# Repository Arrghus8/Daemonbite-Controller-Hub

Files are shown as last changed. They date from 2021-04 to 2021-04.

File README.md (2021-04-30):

# Daemonbite-Controller-Hub

daemonbite-controller-hub

This is an add-on board for the MiSTer FPGA project to provide original hardware inputs for SNES, NES and Genesis controllers using Daemonbite adapters (see https://github.com/MickGyver/DaemonBite-Retro-Controllers-USB). The current version serves only as a mount for the Arduinos and controller ports.

# Parts needed (v0.1):

- 2x Pro Micro ATmega32U4 (micro USB): https://www.aliexpress.com/item/1005001335338291.html
- 2x Micro USB cable: https://www.aliexpress.com/item/4000378492248.html
- 2x DB9 male port: https://www.aliexpress.com/item/33047048440.html
- 2x SNES port (90 degree): https://www.aliexpress.com/item/32838396935.html
- 2x NES port (90 degree): https://www.aliexpress.com/item/32875874969.html
- 4x M3 Male 6mm x M3 Female 20mm Standoff: https://www.aliexpress.com/item/32667773402.html

# Roadmap

- Integrate ATmega32U4 directly on board
- Integrate 7-port powered USB hub to board

# Issues

- Need to verify that 4 controllers (2x SNES and 2x NES) can be run through a single Pro Micro (see https://github.com/MickGyver/DaemonBite-Retro-Controllers-USB/issues/3).

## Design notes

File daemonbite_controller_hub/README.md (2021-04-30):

KiCad Version: (5.99.0-9987-g41839f7e3f), release build

<code>ARDUINO PRO MICRO.STEP</code> taken from https://grabcad.com/library/arduino-pro-micro-1.

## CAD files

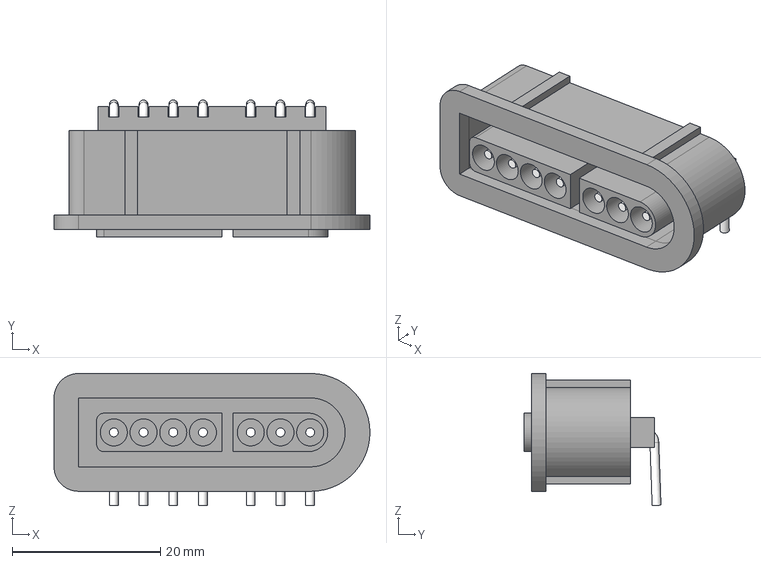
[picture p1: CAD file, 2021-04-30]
daemonbite_controller_hub/SNES_port.step
42.7 x 18.5 x 17.8 mm

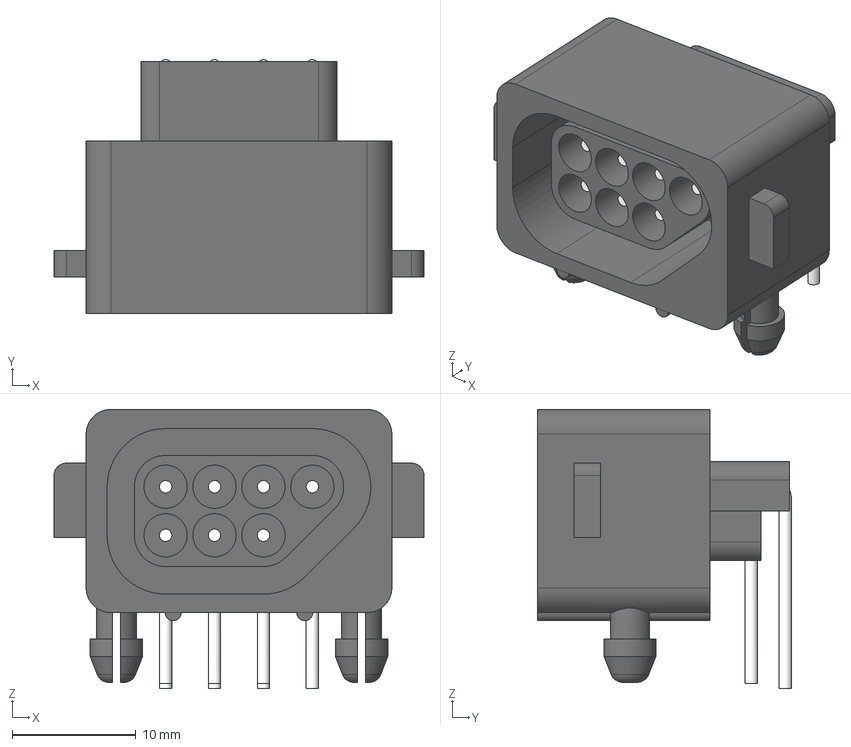
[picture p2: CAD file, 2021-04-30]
daemonbite_controller_hub/NES_port.step
30.0 x 20.5 x 22.6 mm

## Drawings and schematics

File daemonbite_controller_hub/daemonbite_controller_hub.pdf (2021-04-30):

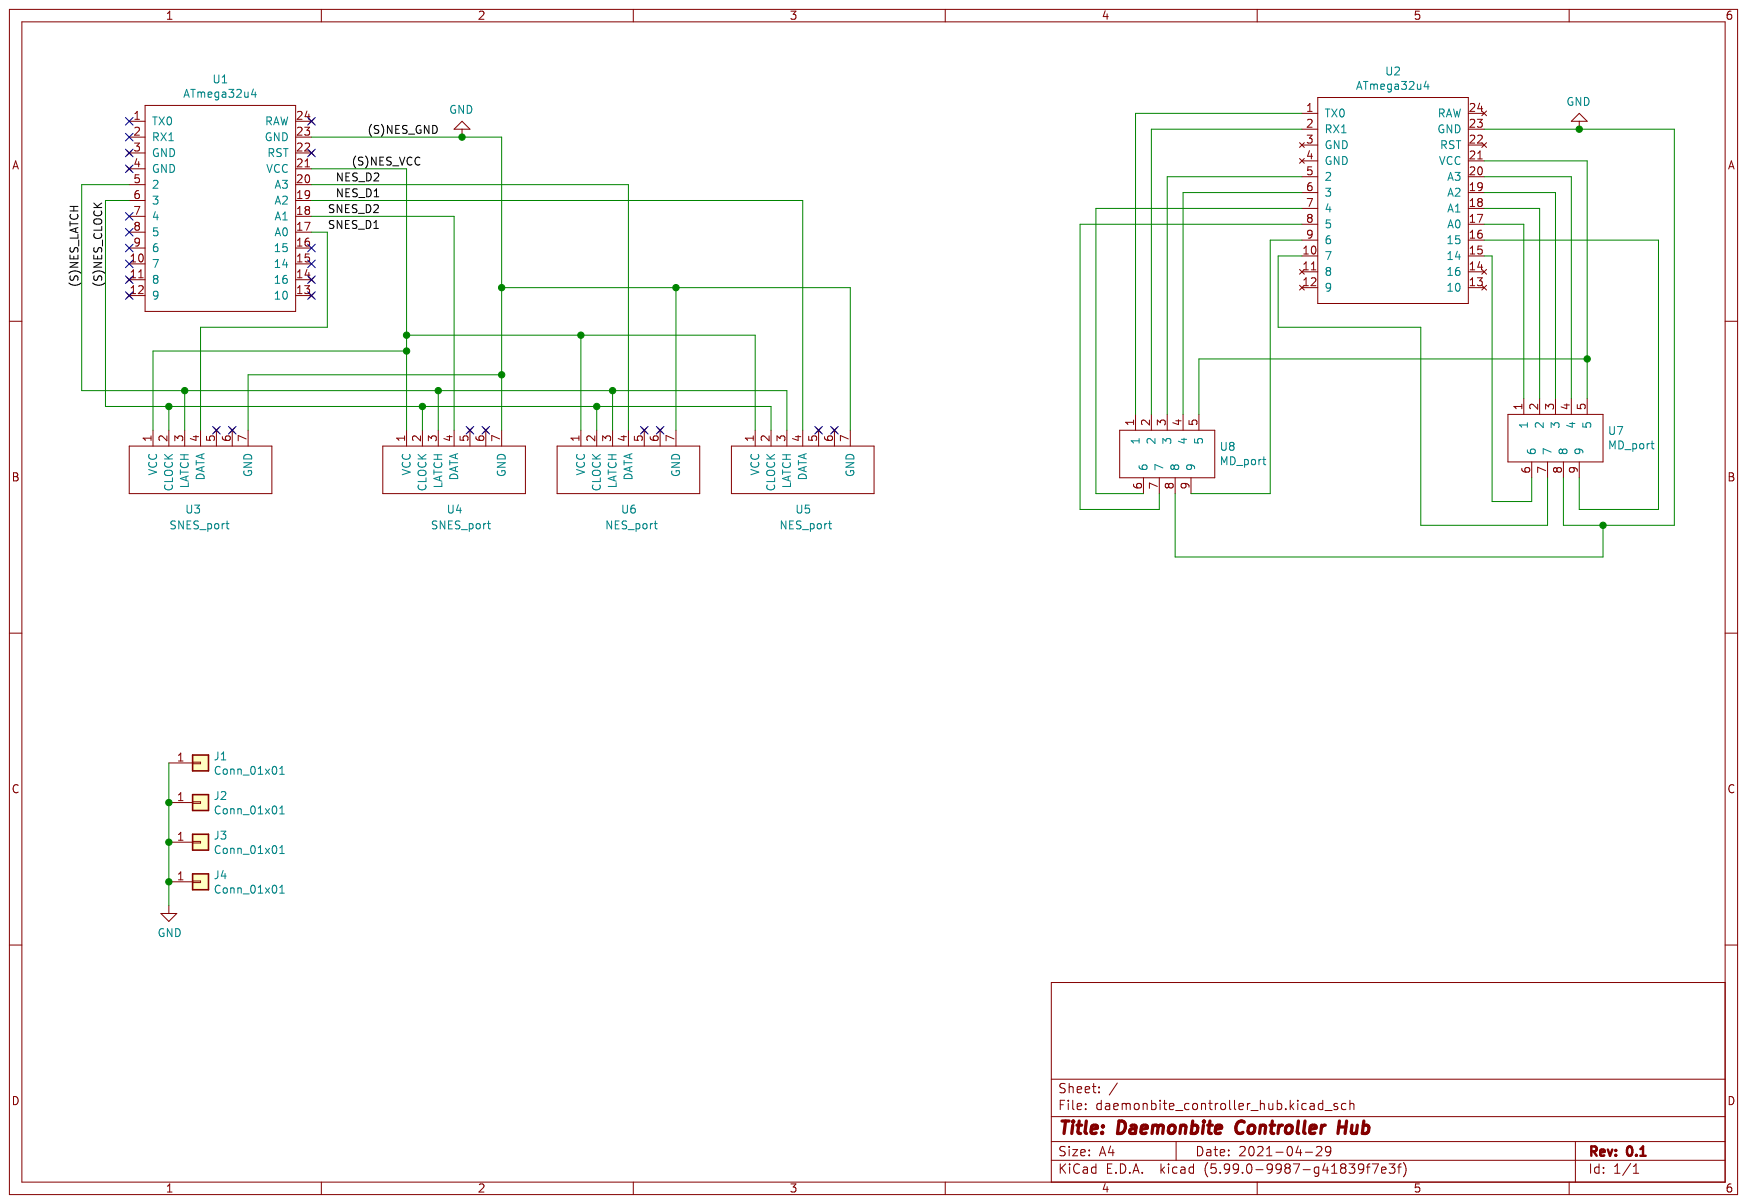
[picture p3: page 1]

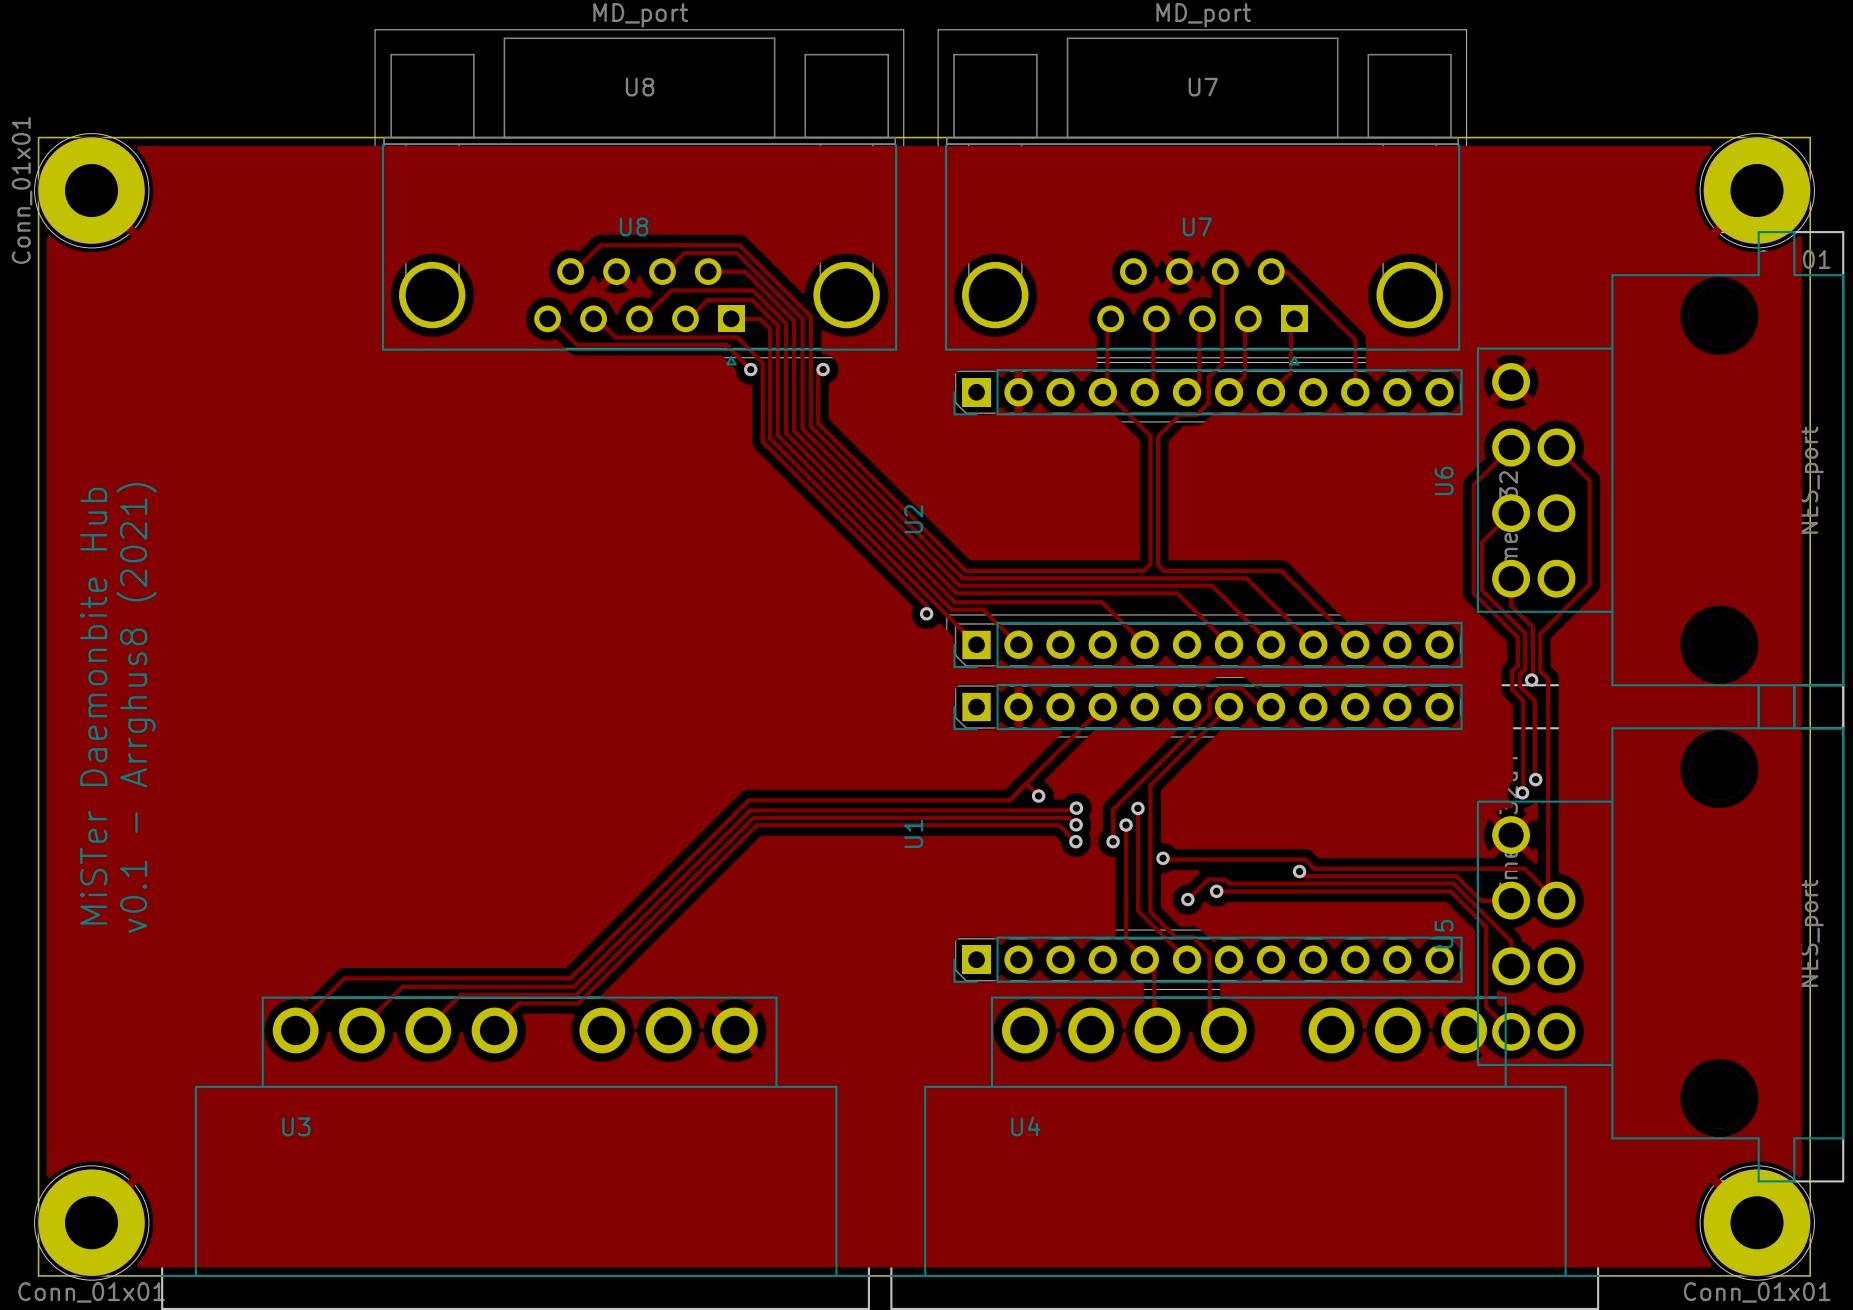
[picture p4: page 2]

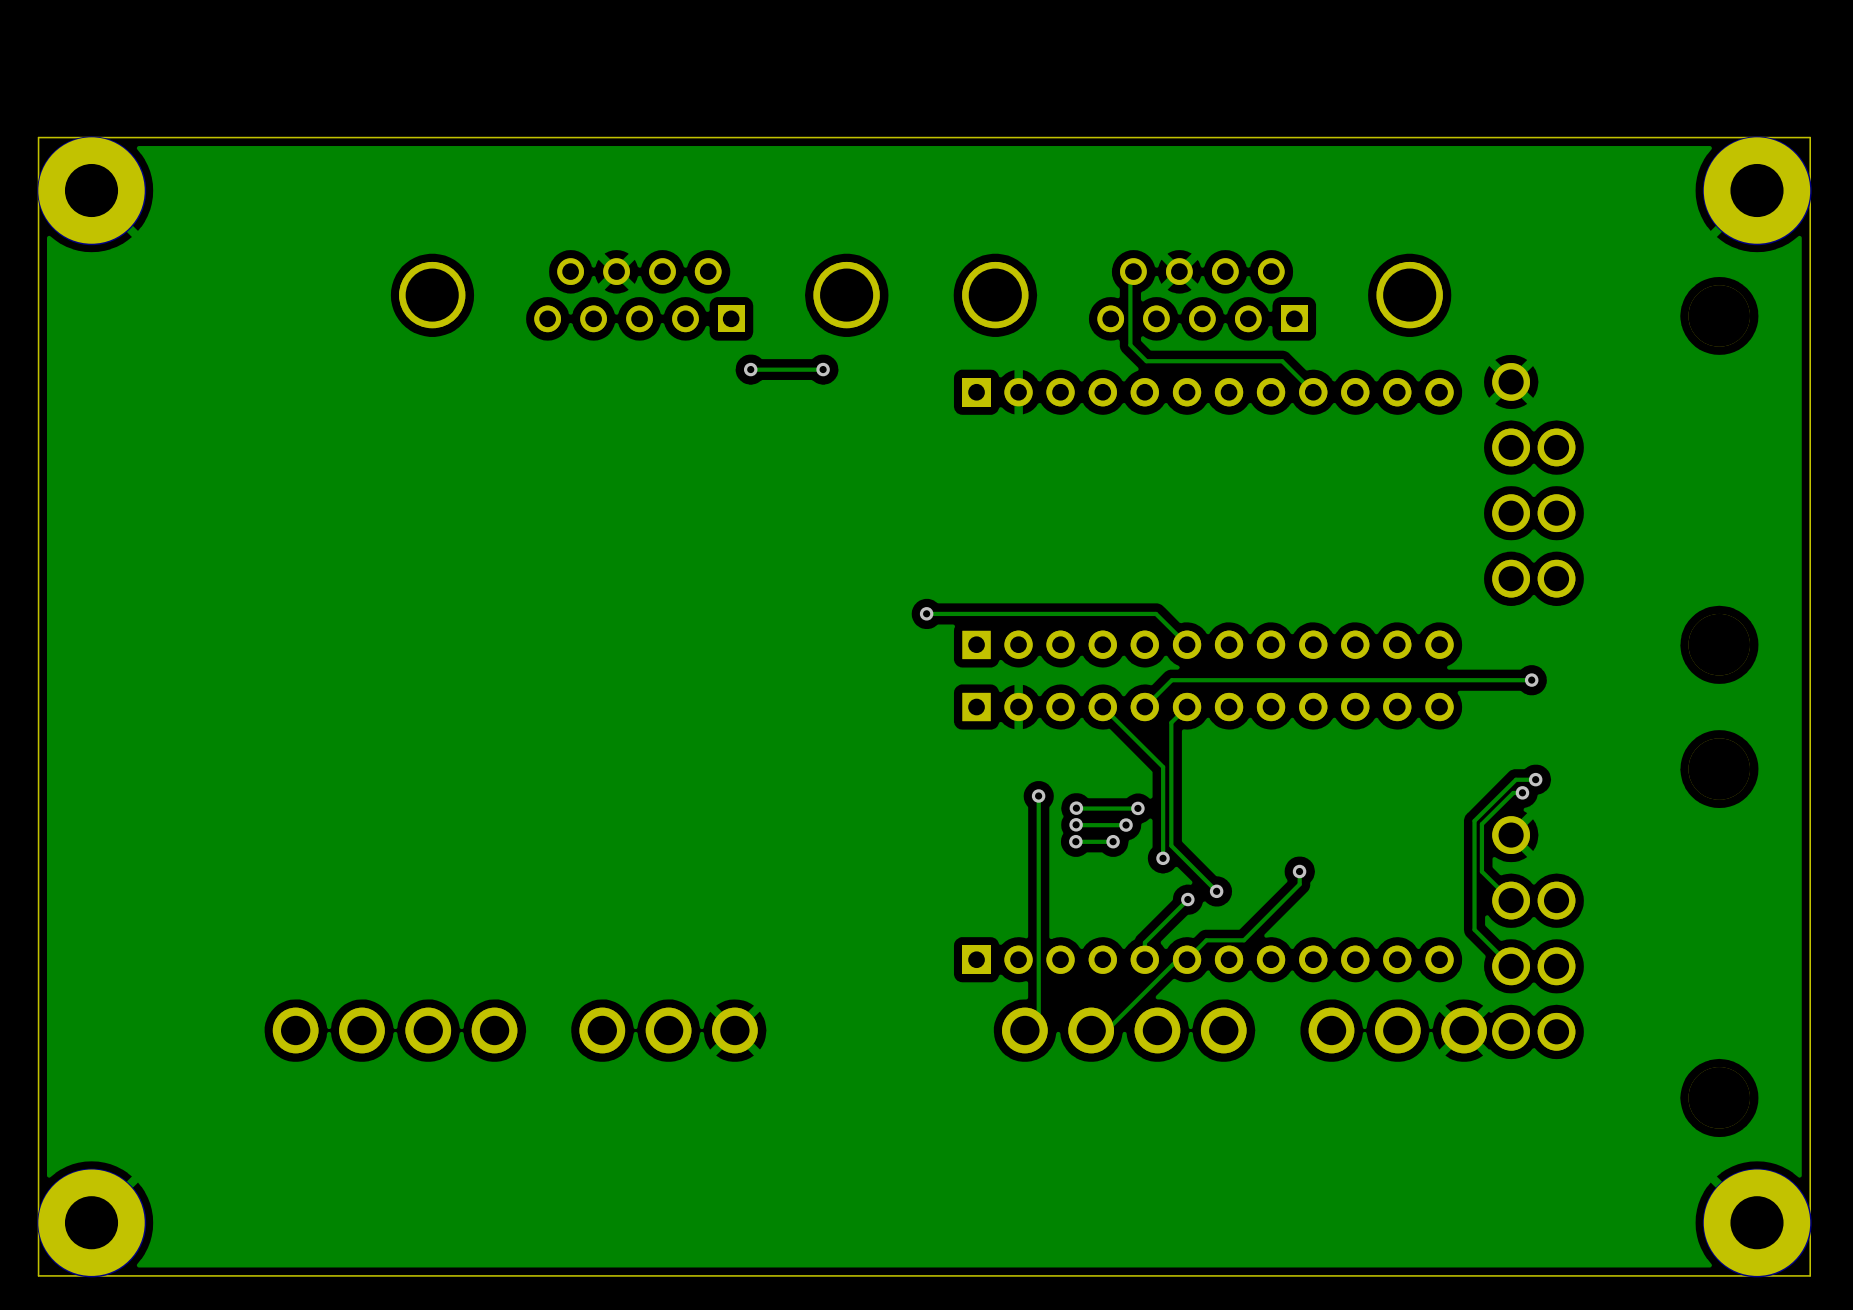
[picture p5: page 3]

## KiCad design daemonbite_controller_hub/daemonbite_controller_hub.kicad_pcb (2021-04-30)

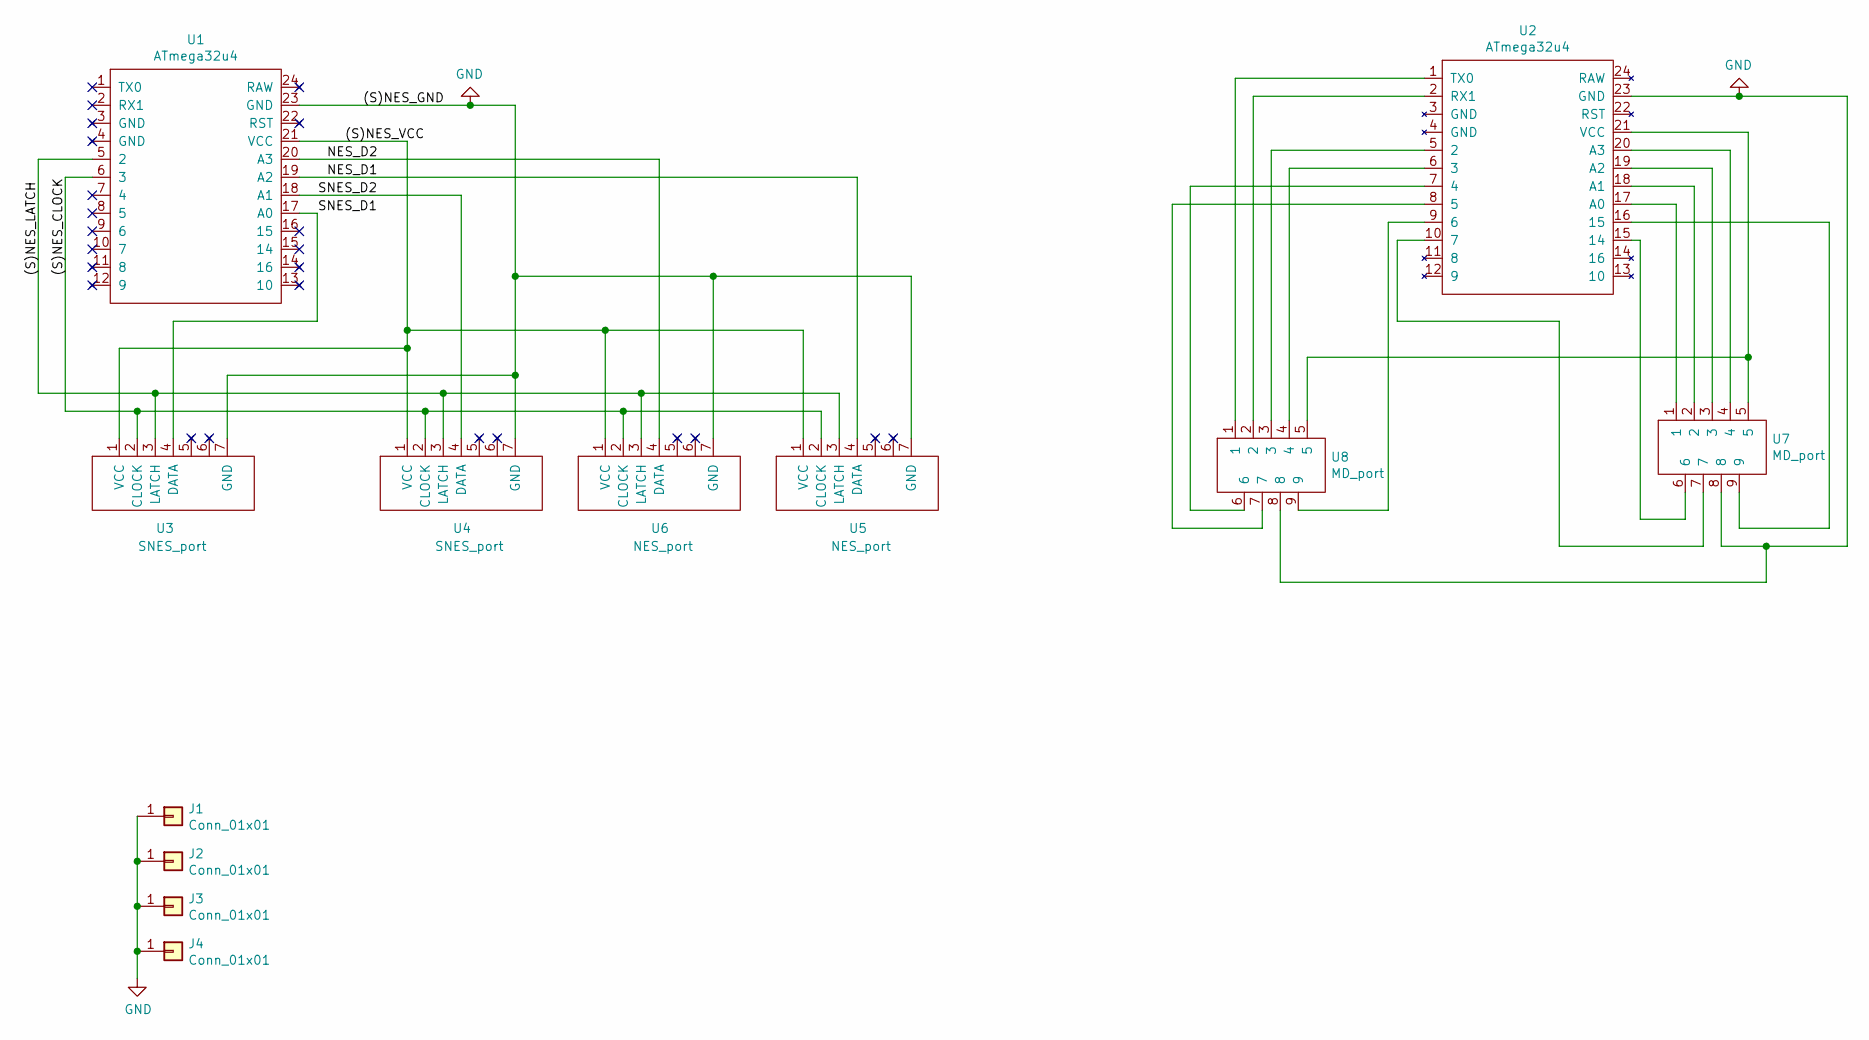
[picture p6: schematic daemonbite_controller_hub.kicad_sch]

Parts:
J1, J2, J3, J4: Conn_01x01; MountingHole_3.2mm_M3_Pad
U1, U2: ATmega32u4; ATmega32U4
U3, U4: SNES_port
U5, U6: NES_port
U7, U8: MD_port; DSUB-9_Male_Horizontal_P2.77x2.84mm_EdgePinOffset7.70mm_Hou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

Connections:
/(S)NES_CLOCK: U1.6 (3), U3.2 (CLOCK), U4.2 (CLOCK), U5.2 (CLOCK), U6.2 (CLOCK)
/(S)NES_LATCH: U1.5 (2), U3.3 (LATCH), U4.3 (LATCH), U5.3 (LATCH), U6.3 (LATCH)
/(S)NES_VCC: U1.21 (VCC), U3.1 (VCC), U4.1 (VCC), U5.1 (VCC), U6.1 (VCC)
/NES_D1: U1.19 (A2), U5.4 (DATA)
/NES_D2: U1.20 (A3), U6.4 (DATA)
/SNES_D1: U1.17 (A0), U3.4 (DATA)
/SNES_D2: U1.18 (A1), U4.4 (DATA)
GND: J1.1, J2.1, J3.1, J4.1, U1.23 (GND), U2.23 (GND), U3.7 (GND), U4.7 (GND), U5.7 (GND), U6.7 (GND), U7.8, U8.8
unnamed: U2.1 (TX0), U8.1
unnamed: U2.2 (RX1), U8.2
unnamed: U2.5 (2), U8.3
unnamed: U2.6 (3), U8.4
unnamed: U2.7 (4), U8.6
unnamed: U2.8 (5), U8.7
unnamed: U2.9 (6), U8.9
unnamed: U2.10 (7), U7.7
unnamed: U2.15 (14), U7.6
unnamed: U2.16 (15), U7.9
unnamed: U2.17 (A0), U7.1
unnamed: U2.18 (A1), U7.2
unnamed: U2.19 (A2), U7.3
unnamed: U2.20 (A3), U7.4
unnamed: U2.21 (VCC), U7.5, U8.5

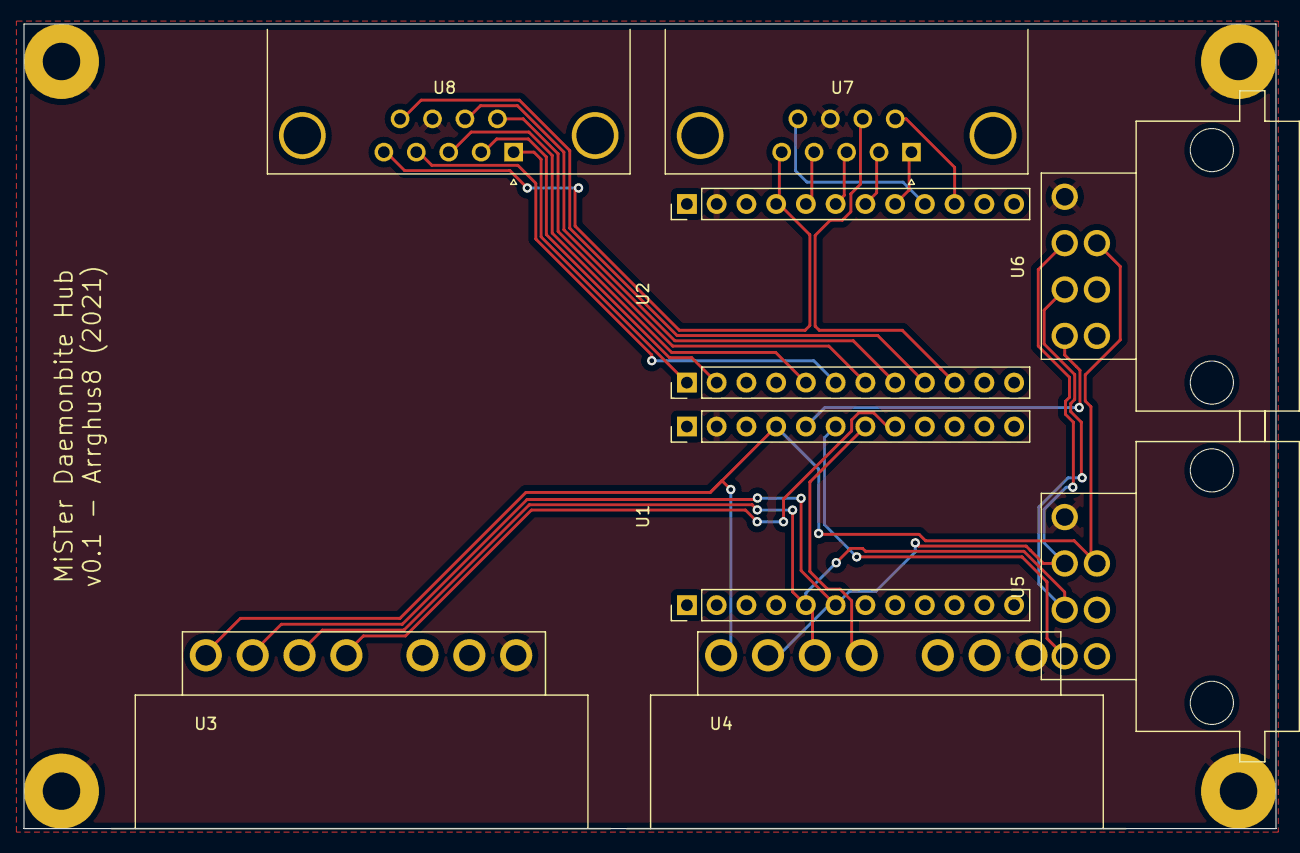
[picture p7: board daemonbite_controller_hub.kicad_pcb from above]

Board: 2 copper layers, 106.9 x 68.7 mm, 12 parts (0 on the bottom side), 23 nets.

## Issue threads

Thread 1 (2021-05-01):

I like it. A few questions and help.

Klausus, 2021-05-01:
Hello. I like your project.
This even serves to be used in a pc, or raspberry as a USB controller adapter (putting it in a 3D printed box).
Or use in a mister fpga also.

**PCB doubts:**
How big is the pcb ? 68.6x107mm ?
Where can I have it made cheaply?
Do you recommend any website?
For example JLPCB ? (I never printed pcb, sorry 4 questions).

**SEGA/DB9 software (Arduino on the right):**
I imagine you have used the same pinout as MickGyver's SegaTwoControollers:
https://github.com/MickGyver/DaemonBite-Retro-Controllers-USB/tree/master/SegaTwoControllersUSB
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

**Nintendo Software (Aduino on the left):**
If you use MickGyver's software you will only have support for the 2 controllers (the controller pinout in your pcb is snes controllers).

You can try to use Mike11S software which I think uses your same pinout:
https://github.com/MikeS11/DaemonBite-Retro-Controllers-USB/tree/master/DualControllersUSB
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

If it doesn't work well you have the jroth project for 5 snes controllers (even if you only use 4).
The data pinout of the controllers does not match, you should modify the arudino file to use the same pinout.
https://github.com/jroth/DaemonBite-Retro-Controllers-USB/tree/master/SNESControllersUSB5Player
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

**Note:**
I don't know which of the 2 snes projects has a lower input lag.
Mike11S supports NTT controllers and in theory that increases the input lag (that's why MickGyver has 2 SNES versions one with NTT controller support and one without NTT support).

I hope you find the github I mentioned helpful.
Thanks 4 All.

Arrghus8, 2021-05-01:
This is great, thanks for the links!

The PCB is 68.7mm x 106.9mm.  My main thought is definitely for use with the MiSTer project, but I agree it could easily be used as a generic USB controller adapter.  I ordered a batch of 3 on https://aisler.net/ for ~$20 shipped, which seems a decent enough deal to me.

Both Arduinos use MickGyver's code and pinouts.  The only changes I made were setting GAMEPAD_COUNT to 4 and added the HID files to the SNES code based on the suggestion from jroth (https://github.com/MickGyver/DaemonBite-Retro-Controllers-USB/issues/3), but I haven't had luck getting all 4 controllers working.  At the least, 3 seem to be working fine.  I'm definitely interested in trying out jroth's fork.

It would be great if someone could test the latency for all of these options.  If there is a noticable increase caused by >2 controllers on one Arduino, I think the most sensible solution would be to add another Arduino.

ercan1441, 2021-05-04:
Great project! Are there any gerber files available so that we can order the PCB from eg. JLCPCB?

dsoms, 2021-05-21:
Hi @Arrghus8, great project!

Did you get luck getting all 4 controllers working?

I'm thinking on order the PCB. Are you planing to do some modifications?

Thanks!

Arrghus8, 2021-05-21:
I haven't had time to work on this lately, but I should be able to return in a month or so.  The best I was able to manage before taking a break was getting all 4 ports working, but with only 3 working simultaneously.  I still plan to play around with jroth's fork before deciding whether it makes sense to try to fit another Daemonbite adapter.  I briefly tried to change his pinout to match the master code, but I'm not familiar enough with Arduino coding to see what my issue was.

I would encourage waiting for a later revision of the board where it will hopefully be in a more usable state.  On the other hand, if anyone is interested in building one now, I have two spare boards that I'd be happy to get rid of.

dsoms, 2021-05-24:
Thanks @Arrghus8, don't worry and take your time. I'll wait for a later revision of the board ;-)
